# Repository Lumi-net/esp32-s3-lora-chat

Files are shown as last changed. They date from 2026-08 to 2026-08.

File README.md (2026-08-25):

# esp32-s3-lora-chat

**ELC (ESP32-S3 LoRa Chat)** — 基于 ESP32-S3 的 LoRa 点对点聊天设备，支持 T9 键盘输入、LVGL GUI、外部 Flash 存储、WiFi 时间同步和低功耗休眠。

[用户使用手册(凑合看吧 个别地方可能不太对)](USER_MANUAL.md)

PCB见`pcb/`目录，3D模型见`3d/`目录。做的比较粗糙，都是排针连接，因为我不想买一大堆小东西自己焊。

我们使用的各模块品牌（并非打广告，只是为了装配和引脚定义正确，如果你可以自己改代码引脚 重做PCB 重做外壳的话也可以买别的）：
| 模块名称 | 店铺 | 名称 | 备注 |
| --- | ---- | ---- | ---- |
| ESP32-S3开发板 | 深圳市轩特佳电子 | ESP32-S3开发板核心板 ESP32-S3-DevKitC-1 N8R2 N16R8模块板载 | ESP32-S3 N16R8 (随便去淘宝找一家就行。这块板子设计的大家都差不多) |
| LoRa | 泽耀科技 | LoRa模块LLCC68替SX1278射频433无线串口收发模块中继透传远距离 | A39C-T400A22D1a |
| LoRa天线 | 东莞市速波电子有限公司 | lora 433mhz天线470m无线数传315M 510mhz全向高增益外置胶棒SMA | 3DBI 5cm(直头);SMA内针;470-490-510mhz |
| Flash | telesky旗舰店 | W25Q80/16/32/64/128 Flash储存模块 8/16/32/64/128Mbit SPI存储 | W25Q64 |
| LCD | 深圳优智景科技 | 2.4寸TFT LCD显示屏240x320点阵 ST7789驱动高清屏显示屏 | - |
| 键盘 | 欣薇电子企业店 | 4X4矩阵按键 带安装孔 单片机薄膜外扩键盘 直插16按键 | - |

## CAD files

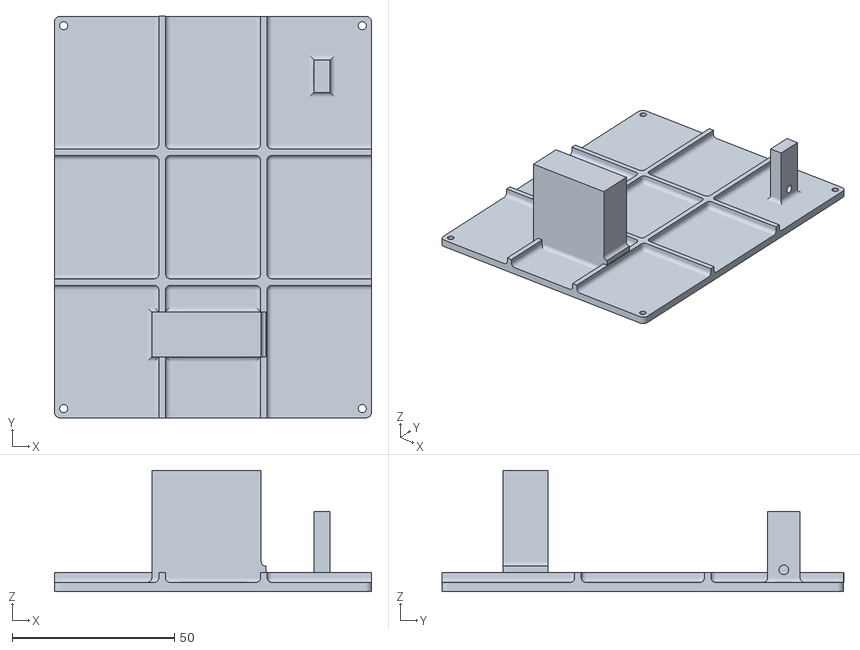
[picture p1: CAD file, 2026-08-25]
3d/底-25.stl
97.8 x 123.9 x 37.3

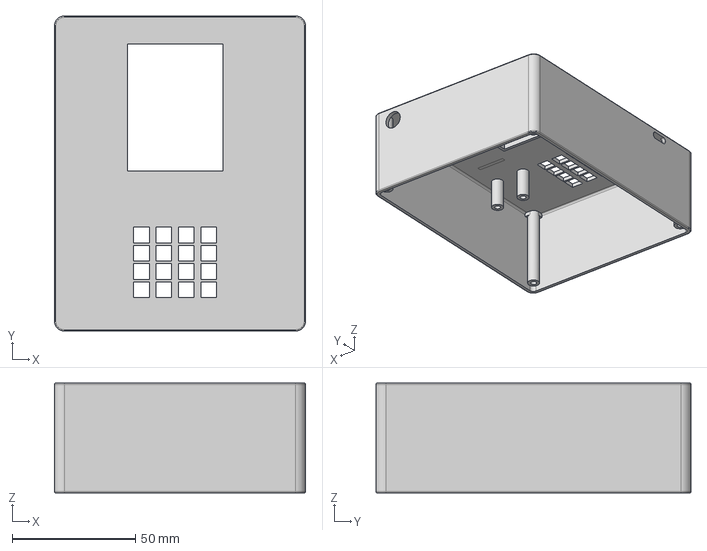
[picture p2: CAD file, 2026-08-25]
3d/esp32-s3-lora-chat.step
102.0 x 128.0 x 44.6 mm

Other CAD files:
3d/大-25.stl
3d/esp32-s3-lora-chat.f3z

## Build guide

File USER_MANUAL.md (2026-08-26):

# ELC (ESP32-S3 LoRa Chat) 用户使用手册

> **Lumi-net** 出品 | 开源 LoRa 点对点通信设备

---

## 目录

- [ELC (ESP32-S3 LoRa Chat) 用户使用手册](#elc-esp32-s3-lora-chat-用户使用手册)
  - [目录](#目录)
  - [1. 快速上手](#1-快速上手)
    - [1.1 前提条件](#11-前提条件)
    - [1.2 开机与启动](#12-开机与启动)
    - [1.3 认识界面](#13-认识界面)
    - [1.4 发送第一条消息](#14-发送第一条消息)
    - [1.5 接收消息](#15-接收消息)
  - [2. 按键操作](#2-按键操作)
    - [2.1 T9 多击输入法](#21-t9-多击输入法)
    - [2.2 锁定/导航模式](#22-锁定导航模式)
  - [3. 界面详解](#3-界面详解)
    - [3.1 状态栏](#31-状态栏)
    - [3.2 菜单页（联系人列表）](#32-菜单页联系人列表)
    - [3.3 聊天页](#33-聊天页)
    - [3.4 输入区域](#34-输入区域)
  - [4. 联系人管理](#4-联系人管理)
    - [4.1 添加联系人](#41-添加联系人)
    - [4.2 删除联系人](#42-删除联系人)
    - [4.3 重命名联系人](#43-重命名联系人)
    - [4.4 联系人 ID 说明](#44-联系人-id-说明)
  - [5. 发送与接收消息](#5-发送与接收消息)
    - [5.1 直发消息](#51-直发消息)
    - [5.2 广播消息（ALL）](#52-广播消息all)
    - [5.3 消息去重](#53-消息去重)
    - [5.4 聊天记录](#54-聊天记录)
  - [6. 设置](#6-设置)
    - [6.1 设置项总览](#61-设置项总览)
    - [6.2 修改联系人别名](#62-修改联系人别名)
    - [6.3 修改用户颜色](#63-修改用户颜色)
    - [6.4 修改界面颜色](#64-修改界面颜色)
    - [6.5 Wi-Fi 配置](#65-wi-fi-配置)
    - [6.6 时间设置](#66-时间设置)
    - [6.7 自动休眠时间](#67-自动休眠时间)
    - [6.8 调节亮度](#68-调节亮度)
    - [6.9 自定义状态栏标题](#69-自定义状态栏标题)
    - [6.10 添加/删除联系人](#610-添加删除联系人)
    - [6.11 清空聊天记录](#611-清空聊天记录)
    - [6.12 恢复出厂设置（清空 NVS）](#612-恢复出厂设置清空-nvs)
    - [6.13 心跳开关](#613-心跳开关)
  - [7. 省电与休眠](#7-省电与休眠)
    - [7.1 自动休眠](#71-自动休眠)
    - [7.2 唤醒方式](#72-唤醒方式)
    - [7.3 快速休眠机制](#73-快速休眠机制)
  - [8. 电池电量](#8-电池电量)
  - [9. 界面颜色自定义](#9-界面颜色自定义)
  - [附录 A：编译与烧录](#附录-a编译与烧录)
    - [环境搭建](#环境搭建)
    - [构建与烧录](#构建与烧录)
    - [关键配置](#关键配置)
  - [附录 B：硬件接线参考](#附录-b硬件接线参考)
    - [主要外设接线](#主要外设接线)
    - [LoRa 模块引脚](#lora-模块引脚)
    - [注意事项](#注意事项)
  - [附录 C：sim\_lora.py 模拟器使用](#附录-csim_lorapy-模拟器使用)
    - [安装依赖](#安装依赖)
    - [基本用法](#基本用法)
    - [交互命令](#交互命令)
    - [示例：测试完整通信流程](#示例测试完整通信流程)
    - [注意事项](#注意事项-1)

---

## 1. 快速上手

### 1.1 前提条件

在使用 ELC 之前，请确认以下事项：

1. **至少准备两台设备**（或一台设备 + 一台运行 `sim_lora.py` 的电脑），单台设备无法进行点对点通信。
2. **设备 ID 已预设**。每台设备有一个唯一的十六进制 ID（如 `0x01`、`0x05`），在固件中硬编码（`self_id` 变量）。如需修改，请重新编译固件。
3. **所有设备使用相同 LoRa 频段和组号**。出厂默认为 470 MHz、组号 `0x00`。如果修改了组号，所有设备必须一致。
4. **建议先设置时间**。消息时间戳依赖 RTC 时钟，未设置时间时消息将显示 `00:00`。

### 1.2 开机与启动

接通电源后，设备显示开机动画：

1. 屏幕中央出现旋转动画（Spinner），下方依次显示初始化状态：
   - `System Booting...`
   - `Initializing Keyboard...`
   - `Initializing UART...`
   - `Initializing Flash...`
   - `Initializing I2C...`
   - `Initializing NVS...`
   - `Reading NVS...`
   - `Restoring Flash Offset...`
   - `Updating Latest Message Time...`
   - `Done!`
2. 初始化完成后自动进入**菜单页**（联系人列表）。

整个启动过程约 3-5 秒。

### 1.3 认识界面

界面分为三个区域：

```
┌─────────────────────────────────┐
│ 10/25 14:30   Lumi-net   🟢 85% │  ← 状态栏（15px）
├─────────────────────────────────┤
│                                 │
│  > Alice        0x01            │
│    02/02 15:37    02/02 14:28   │  ← 在线时间(左) + 消息时间(右)
│                                 │
│    Bob          0x02            │
│    Maybe Offline  No messages   │
│                                 │
│    ...                          │  ← 中间列表区
│                                 │
├─────────────────────────────────┤
│ [S][?]                Please... │  ← 输入区域
│                          112    │
└─────────────────────────────────┘
```

- **状态栏**：左侧显示时间，中间显示标题，右侧显示 LoRa 状态指示灯和电池电量
- **中间列表**：菜单页显示联系人列表，聊天页显示消息记录
- **输入区域**：左侧显示 Shift/Lock 图标和剩余字符数，右侧为文本输入框

### 1.4 发送第一条消息

1. 在菜单页，使用**导航模式**上下选择联系人，按**确认键**进入聊天页。
2. 使用 T9 输入法输入消息（详见 [2.2 节](#22-t9-多击输入法)）。
3. 按 **Shift + CAND4**（即键盘上标有 "SEND" 的位置）发送消息。
4. 等待对方设备确认（ACK）。状态栏指示灯变为**紫色**（等待确认），收到 ACK 后变为**绿色**（空闲）。

### 1.5 接收消息

- 收到消息时，如果当前在聊天页且对象匹配，消息自动追加到列表底部。
- 如果不在聊天页，消息仍然保存到外部闪存（Flash），下次进入聊天页时可查看。

---

## 2. 按键操作

### 2.1 T9 多击输入法

每个键的第一行为小写模式，第二行为大写模式，第三行为导航模式。
```
┌─────┬─────┬─────┬─────┐
│  1abc  │  2def  │  3ghi   │   C1   │
│  !ABC  │  ?DEF  │  'GHI   │        │
│  MENU  │   UP   │SETTINGS │  HOME  │
├─────┼─────┼─────┼─────┤
│  4jkl  │  5mno  │  6pqr  │   C2    │
│  -JKL  │  *MNO  │  /PQR  │         │
│  LEFT  │CONFIRM │  RIGHT │   END   │
├─────┼─────┼─────┼─────┤
│  7stu  │  8vwx  │  9yz(  │   C3    │
│  +STU  │  &VWX  │  ␣YZ)  │         │
│  BACK  │  DOWN  │ DELETE │  PGUP   │
├─────┼─────┼─────┼─────┤
│  SHIFT │  0␣^=  │BACKSPACE│  C4    │
│  SHIFT │  .,:_  │INPUTLOCK│ SEND   │
│  SHIFT │        │BACKSPACE│PGDOWN  │
└─────┴─────┴─────┴─────┘
```

T9 输入法分为两步：**先选键，再选字**。

**第一步：按数字键选键**

按下一个数字键（如 `1`、`2`、`5` 等），屏幕输入区域的锁图标会显示对应的键号（0-9）。此时你已经选中了该键。

**第二步：按候选键选字**

使用C1-C4候选键，选择当前键中的第1-4个候选。

**输入示例**：输入 "Hi"

1. 按 **SHIFT** 键 → Shift 图标变实心（大写模式）
2. 按 `3` 键 → 锁图标显示 `3`（对应字符`'GHI`）
3. 按 **C3** 键 → 选择键 3 的第 3 个候选（Shift 模式），得到 `H`
4. Shift 自动关闭
5. 按 `3` 键 → 锁图标显示 `3`（对应字符 `3ghi`）
6. 按 **C4** 键 → 选择键 3 的第 4 个候选，得到 `i`

### 2.2 锁定导航模式

按下 `Shift + BS` 可切换至锁定导航模式。锁定导航时锁图标显示 `L`。进入锁定导航模式后，需要再次使用`Shift + BS`退出。

锁定模式下，各键变为导航功能：

| 按键 | 功能 |
|---|---|
| `1` | 返回菜单页 |
| `2` | 光标上移 |
| `3` | 进入设置页 |
| `C1` | 光标移至行首（Home） |
| `4` | 光标左移 |
| `5` | **确认/进入**（选择菜单项、进入设置详情） |
| `6` | 光标右移 |
| `C2` | 光标移至行尾（End） |
| `7` | **返回**（从聊天/设置详情返回上级） |
| `8` | 光标下移 |
| `9` | 向前删除（Delete） |
| `C3` | 向上翻页（Page Up） |
| `C4` | 向下翻页（Page Down） |

**典型操作流程**：

1. 开机后在菜单页 → 按 `Shift + BS` 进入锁定模式
2. 按 `2`/`8` 上下选择联系人
3. 按 `5` 确认进入聊天页
4. 再按 `Shift + BS` 退出锁定模式，进入输入模式
5. 输入消息，按 `Shift + C4`（SEND）发送
6. 按 `Shift + BS` 进入锁定模式，按 `1` 或 `7` 返回菜单

---

## 3. 界面详解

### 3.1 状态栏

状态栏位于屏幕最顶部（15px 高），从左到右显示：

| 位置 | 内容 | 说明 |
|---|---|---|
| 左侧 | 时间 `MM/DD HH:MM` | 未设置时间时显示 `Set Time First!` |
| 中间 | 自定义标题 | 默认 `Lumi-net`，最多 16 字符 |
| 右侧 | LoRa 状态指示灯 | 彩色小方块，见下表 |
| 右侧 | 心跳指示灯 | 橙色小方块，仅在心跳**关闭**时显示 |
| 最右 | 电池百分比 | 如 `85%` |

**LoRa 状态指示灯颜色含义**：

| 颜色 | 状态 | 含义 |
|---|---|---|
| 🟢 绿色 | IDLE | 空闲，可收发 |
| 🔵 蓝色 | RECEIVING | 正在接收数据 |
| 🟡 黄色 | SENDING | 正在发送数据 |
| 🟣 紫色 | WAITING_ACK | 已发送，等待对方确认 |
| 🔴 红色 | TIMEOUT | 确认超时，发送失败 |

### 3.2 菜单页（联系人列表）

菜单页是设备的默认首页，显示所有已添加的联系人。

每个联系人显示两行信息：

```
> Alice         0x01          ← 第一行：别名 + 十六进制 ID
  02/02 15:37   02/02 14:28   ← 第二行：在线时间(左) + 消息时间(右)
```

- **光标 `>`** 指示当前选中的联系人
- 每页最多显示 5 个联系人，超出部分可通过翻页查看
- 排序方式：按 ID 从小到大
- 内置联系人 `ALL`（ID `0x00`）始终在列表最前面
- **在线时间**（左侧 `MM/DD HH:MM`）：该联系人最后一次被听到的时间（收到心跳或普通消息均会更新）。如果从未收到过任何通信，显示 `Maybe Offline`。
- **消息时间**（右侧 `MM/DD HH:MM`）：最后一次与该联系人交换消息的时间（发送或接收均会更新）。如果没有消息记录，显示 `No messages`。

### 3.3 聊天页

进入某个联系人的聊天页后，顶部显示标题：

```
CHAT | Alice (0x01)
```

消息列表格式：

```
02/02                     ← 日期分隔线（仅在日期变化时出现）
14:28 Alice: Hello!       ← [时间] [别名]: [消息内容]
14:29 Bob: How are you?   ← 对方消息
14:30 Alice: I'm fine.    ← 我的消息
```

- 消息内容自动换行
- 新消息自动追加到底部并滚动
- 向上滚动可加载更早的消息（每次加载 10 条）

### 3.4 输入区域

屏幕底部的输入区域包含：

```
[S][?]  Please Input...
   112
```

- **Shift 图标 `[S]`**：实心背景表示大写模式已开启，透明背景表示普通模式
- **Lock 图标 `[?]`**：显示 `L` 表示锁定模式，显示数字表示正在选键，显示 `?` 表示普通模式
- **输入框**：显示输入的文本，支持多行
- **剩余字符数**：左下角数字，最大 120 字符

---

## 4. 联系人管理

### 4.1 添加联系人

1. 进入**设置页**（按 `SETTINGS`）
2. 选择 **Add/Remove a contact**，按 `CONFIRM` 确认
3. 输入目标设备的十六进制 ID（如 `02`），按确认
4. 输入该联系人的别名（如 `Bob`），按确认
5. 联系人添加成功，自动返回设置页

**注意事项**：
- ID `0x00`（ALL）和 `0xFF` 为保留值，不允许添加
- 如果输入的 ID 已存在，会进入删除确认流程（见 4.2 节）

### 4.2 删除联系人

1. 在 **Add/Remove a contact** 中输入要删除的联系人 ID
2. 如果该 ID 已存在，设备显示确认提示：

   ```
   Delete contact 0x02 [Bob]?
   Type "0x02Bob" to confirm delete.
   ```

3. 输入 `0x` + ID + 别名（如 `0x02Bob`）进行确认
4. 输入错误则取消删除

**注意**：内置联系人 `ALL`（ID `0x00`）无法删除。

### 4.3 重命名联系人

1. 进入**设置页**
2. 选择 **Change Alias**
3. 输入要修改的联系人 ID，按确认
4. 输入新的别名，按确认
5. 别名更新成功，立即生效

### 4.4 联系人 ID 说明

- 每台设备的 ID 在固件中通过 `self_id` 变量定义（硬编码在 `uart.c` 中）
- 默认 ID 为 `0x01`
- 修改 ID 需要重新编译固件
- 所有设备的 ID 必须互不相同
- 只有添加了别名的联系人才会出现在菜单中；未添加别名的 ID 不会显示
- 收到来自未知 ID 的消息时，消息写入 Flash 但不更新菜单；后续手动添加该 ID 为联系人后，聊天页会从 Flash 加载历史消息

---

## 5. 发送与接收消息

### 5.1 直发消息

直发消息是点对点通信，需要对方设备自动确认收到（ACK）。

**发送流程**：
1. 进入目标联系人的聊天页
2. 输入消息（最多 120 字符）
3. 按 **Shift + C4**（SEND）发送
4. 状态栏指示灯变为**紫色**（等待 ACK）
5. 3 秒内收到 ACK → 消息保存成功，指示灯恢复**绿色**
6. 3 秒内未收到 ACK → 自动重试，最多重试 5 次
7. 5 次均超时 → 显示错误提示 `Message failed to send!`

**注意事项**：
- 发送期间（等待 ACK 时）无法发送新消息
- 对方设备需要在线且在通信范围内，否则会发送失败。
- 即使对方设备未将你添加为联系人，消息仍然会被接收，但不会自动出现在菜单中（无法看到）。如果之后对方手动添加你的 ID 为联系人，打开聊天页时会从 Flash 加载历史消息并显示。

### 5.2 广播消息（ALL）

广播消息发送给所有设备，无需确认ACK。

1. 在菜单页选择 **ALL**（ID `0x00`）进入聊天页
2. 输入消息并发送
3. 消息立即保存到本地 Flash，无需等待 ACK
4. 通信范围内所有设备均可收到

**广播消息特点**：
- 不需要对方确认
- 不保证送达
- 消息同时保存在本地和对方设备（若能收到）

### 5.3 消息去重

设备通过序列号（seq）机制自动去除重复消息。如果同一条消息因重试等原因被多次接收，只有第一条会被处理，后续重复消息被静默丢弃。

### 5.4 聊天记录

- 所有收发的消息都保存在外部 SPI Flash（约 8MB）
- 采用 A/B 块磨损均衡机制，延长 Flash 寿命
- 开机时自动扫描恢复写入位置
- 支持跨 A/B 块的连续读取
- 可在设置中清空聊天记录（需输入确认码）

---

## 6. 设置

### 6.1 设置项总览

| # | 设置项 | 功能简述 |
|---|---|---|
| 0 | Change Alias | 修改联系人显示名称 |
| 1 | Change User Color | 修改联系人消息颜色 |
| 2 | Change Interface Color | 修改界面主题颜色（6 个可配置项） |
| 3 | Wi-Fi (For Time) | 配置 Wi-Fi 用于时间同步 |
| 4 | Time | 手动设置时间或通过 Wi-Fi NTP 同步 |
| 5 | Auto Sleep Time | 设置自动休眠超时时间（秒） |
| 6 | Change Brightness | 调节屏幕亮度（10-100） |
| 7 | Customize Title | 自定义状态栏标题（最多 16 字符） |
| 8 | Add/Remove a contact | 添加或删除联系人 |
| 9 | Clear Chat History | 清空外部 Flash 中的聊天记录 |
| 10 | Clear NVS Data | 恢复出厂设置（清除所有设置，重启） |
| 11 | Heartbeat Enable | 开启/关闭心跳广播 |

### 6.2 修改联系人别名

1. 设置页 → **Change Alias** → 确认
2. 输入目标联系人的十六进制 ID（如 `01`）→ 确认
3. 输入新的别名（最多 16 字符）→ 确认
4. 别名立即生效

**注意**：如果输入的 ID 不存在，会提示 `Invalid ID!`。

### 6.3 修改用户颜色

为每个联系人设置独特的消息显示颜色。

1. 设置页 → **Change User Color** → 确认
2. 输入目标联系人的十六进制 ID → 确认
3. 输入 6 位十六进制颜色值（如 `00FF00` 表示绿色）→ 确认

颜色值格式：`RRGGBB`（红绿蓝各 2 位十六进制）。

### 6.4 修改界面颜色

界面有 6 个可配置颜色项：

| 索引 | 名称 | 说明 |
|---|---|---|
| 0 | COLOR_BACKGROUND | 页面背景色 |
| 1 | COLOR_MSG_TEXT | 消息文本颜色 |
| 2 | COLOR_MSG_TIME | 消息时间标签颜色 |
| 3 | COLOR_MSG_DATE | 日期分隔线颜色 |
| 4 | COLOR_STATUS_BAR | 状态栏背景色 |
| 5 | COLOR_TEXTAREA_BACKGROUND | 输入框背景色 |

操作步骤：
1. 设置页 → **Change Interface Color** → 确认
2. 输入颜色索引（0-5）→ 确认
3. 输入 6 位十六进制颜色值 → 确认

### 6.5 Wi-Fi 配置

Wi-Fi 仅用于时间同步（NTP），不用于消息传输。

**方式一：手动输入 SSID 和密码**

1. 设置页 → **Wi-Fi (For Time)** → 确认
2. 输入 Wi-Fi 名称（SSID，最多 32 字符）→ 确认
3. 输入 Wi-Fi 密码（至少 8 位）→ 确认
4. 设备自动连接 Wi-Fi，同步时间后关闭 Wi-Fi

**方式二：热点配网（Soft-AP）**

1. 设置页 → **Wi-Fi (For Time)** → 确认
2. **不输入任何内容**，直接按确认
3. 设备启动热点 `ESP32S3_Config`，屏幕显示随机密码
4. 用手机连接该热点，打开浏览器访问 `192.168.4.1`
5. 在网页中输入目标 Wi-Fi 的 SSID 和密码，提交
6. 设备自动切换到 STA 模式连接 Wi-Fi，同步时间后关闭

**注意事项**：
- 热点模式有 5 分钟超时，超时后自动关闭
- Wi-Fi 连接成功后会自动关闭以节省电量
- 时间同步使用 `ntp.aliyun.com`（主）和 `pool.ntp.org`（备）

### 6.6 时间设置

**手动设置**：
1. 设置页 → **Time** → 确认
2. 输入格式：`YYYYMMDDHHMMSS`（如 `20260202114514` 表示 2026 年 2 月 2 日 11:45:14）
3. 按确认，时间立即生效

**Wi-Fi NTP 同步**：
1. 设置页 → **Time** → 确认
2. **不输入任何内容**，直接按确认
3. 设备自动连接已保存的 Wi-Fi 并同步时间
4. 同步成功后显示 `Time Synced!`，Wi-Fi 自动关闭

时区固定为 UTC+8（中国标准时间）。

### 6.7 自动休眠时间

设置设备无操作后自动进入休眠的超时时间。

1. 设置页 → **Auto Sleep Time** → 确认
2. 输入超时秒数（如 `300` 表示 5 分钟）
3. 按确认

默认值为 300 秒（5 分钟）。设为 0 可禁用自动休眠。我们不建议禁用自动休眠，因为这将会非常耗电。

### 6.8 调节亮度

1. 设置页 → **Change Brightness** → 确认
2. 输入亮度值（10-100，如 `50`）
3. 按确认，亮度立即生效

亮度值 10 为最暗，100 为最亮。设置保存在 NVS 中，重启后仍然有效。

### 6.9 自定义状态栏标题

1. 设置页 → **Customize Title** → 确认
2. 输入新标题（最多 16 字符）
3. 按确认，标题立即更新

默认标题为 `Lumi-net`。

### 6.10 添加/删除联系人

详见 [第 4 章](#4-联系人管理)。

### 6.11 清空聊天记录

此操作会擦除整个外部 Flash 芯片（约 8MB），**所有聊天记录将永久丢失**。

1. 设置页 → **Clear Chat History** → 确认
2. 屏幕显示随机 4 位确认码（如 `A3F2`）
3. 输入 `CLEAR FLASH` + 空格 + 确认码（如 `CLEAR FLASH A3F2`）
4. 按确认，开始擦除（约 1 分钟）
5. 擦除完成后显示 `Flash cleared.`

**请谨慎操作！此操作不可逆。**

### 6.12 恢复出厂设置（清空 NVS）

此操作会清除所有 NVS 存储的设置（别名、颜色、亮度、Wi-Fi 配置等），并自动重启设备。

1. 设置页 → **Clear NVS Data** → 确认
2. 屏幕显示随机 4 位确认码
3. 输入 `CLEAR NVS` + 空格 + 确认码
4. 按确认，设备清除 NVS 后自动重启

**注意**：重启后所有设置恢复默认值，但聊天记录（存储在外部 Flash）不受影响。

### 6.13 心跳开关

心跳广播用于让其他设备知道你在线，默认开启，但关闭可以省电。

1. 设置页 → **Heartbeat Enable** → 确认
2. 屏幕显示当前状态（`ON` 或 `OFF`）
3. 按确认切换状态

- 开启时：设备每 3-4 分钟自动发送一次心跳广播
- 关闭时：状态栏显示橙色指示灯作为警告
- 心跳关闭后，其他设备将无法看到你的在线状态

---

## 7. 省电与休眠

### 7.1 自动休眠

设备在无操作超过设定时间（默认 300 秒）后自动进入睡眠模式。

进入休眠前的条件：
- 无待发送/待确认的消息
- Wi-Fi 处于空闲状态
- 无按键按下、无 LoRa 数据收发

休眠时：
- 屏幕背光关闭
- CPU 进入低功耗模式
- LoRa 模块进入休眠
- RTC 时钟继续运行

### 7.2 唤醒方式

| 唤醒源 | 触发条件 | 行为 |
|---|---|---|
| 键盘（EXT1） | 任意按键按下 | 亮屏 |
| LoRa AUX（EXT0） | AUX 引脚（GPIO21）变低 | 不亮屏，但保持唤醒 5 秒以处理消息 |
| 定时器 | 心跳发送时间 | 不亮屏，发送完心跳重新休眠 |

### 7.3 快速休眠机制

当设备被 LoRa AUX 或定时器唤醒时，会启动一个 5 秒的"快速休眠截止时间"：
- 在这 5 秒内收到新消息 → 重新计时 5 秒
- 5 秒内无活动 → 自动重新休眠
- 键盘唤醒不触发此机制，保持唤醒直到超时

---

## 8. 电池电量

ELC 支持 INA219 电流/电压传感器（I2C 地址 `0x40`），可监测电池电量。

- 电量每 30 秒更新一次
- 显示在状态栏最右侧（如 `85%`）
- 电压范围：3.30V（0%）至 4.20V（100%）
- 电量变化小于 1% 时不更新显示（防抖动）
- LoRa 发送或 Wi-Fi 活动期间跳过读取（避免电压跌落导致误判）

---

## 9. 界面颜色自定义

ELC 支持完全自定义界面颜色。所有颜色以 6 位十六进制值（`RRGGBB`）存储在 NVS 中。

**可配置的颜色项**：

| 索引 | NVS 键名 | 说明 | 默认值 |
|---|---|---|---|
| 0 | ic_0 | 背景色 | 深色 |
| 1 | ic_1 | 消息文本色 | 白色 |
| 2 | ic_2 | 消息时间色 | 灰色 |
| 3 | ic_3 | 日期分隔线色 | 灰色 |
| 4 | ic_4 | 状态栏背景色 | 深色 |
| 5 | ic_5 | 输入框背景色 | 深色 |

**每个联系人也有独立的颜色**（用户颜色），用于在聊天中区分不同人的消息。

修改方式详见 [6.3 节](#63-修改用户颜色) 和 [6.4 节](#64-修改界面颜色)。

---

## 附录 A：编译与烧录

### 环境搭建

请参考 [ESP-IDF 官方安装指南](https://docs.espressif.com/projects/esp-idf/en/latest/esp32s3/get-started/)。

推荐下载 `.zst` 离线安装包，避免在线安装的网络问题。

### 构建与烧录

```bash
# 设置目标芯片
idf.py set-target esp32s3

# 编译
idf.py build

# 烧录并打开串口监视器（替换 PORT 为实际串口号，如 COM7、/dev/ttyUSB0）
idf.py -p PORT flash monitor
```

### 关键配置

| 配置项 | 值 | 说明 |
|---|-----|---|
| Flash Size | 16MB (QIO 80MHz) | 外部 Flash 容量 |
| 分区表 | `partitions_user.csv` | 自定义分区（factory app @ 0x10000, 4MB） |
| PSRAM | 启用 | LVGL 显示缓冲使用 PSRAM |

---

## 附录 B：硬件接线参考

### 主要外设接线

| 外设 | GPIO | 功能 | 说明 |
|---|---|---|---|
| **键盘行** | GPIO 5, 6, 7, 4 | 输出（开漏） | 矩阵键盘行线 |
| **键盘列** | GPIO 16, 17, 18, 8 | 输入（上拉） | 矩阵键盘列线，支持 EXT1 唤醒 |
| **LoRa UART TX** | GPIO 19 | UART1 TX | 连接 LoRa 模块 RX |
| **LoRa UART RX** | GPIO 20 | UART1 RX | 连接 LoRa 模块 TX |
| **LoRa MD0** | GPIO 47 | 输出 | 模式控制 0 |
| **LoRa MD1** | GPIO 48 | 输出 | 模式控制 1 |
| **LoRa AUX** | GPIO 21 | 输入（上拉） | 模块状态指示，支持 EXT0 唤醒 |
| **LCD SPI MOSI** | GPIO 11 | SPI2 MOSI | LCD 数据线 |
| **LCD SPI SCLK** | GPIO 12 | SPI2 SCLK | LCD 时钟线 |
| **LCD CS** | GPIO 10 | 输出 | LCD 片选 |
| **LCD DC** | GPIO 13 | 输出 | LCD 数据/命令选择 |
| **LCD Reset** | GPIO 14 | 输出 | LCD 复位 |
| **LCD 背光** | GPIO 9 | LEDC PWM | 亮度控制 |
| **Flash MISO** | GPIO 41 | SPI3 MISO | 外部 Flash 数据输入 |
| **Flash MOSI** | GPIO 38 | SPI3 MOSI | 外部 Flash 数据输出 |
| **Flash CLK** | GPIO 39 | SPI3 CLK | 外部 Flash 时钟 |
| **Flash CS** | GPIO 40 | 输出 | 外部 Flash 片选 |
| **I2C SDA** | GPIO 42 | I2C 数据 | INA219 电池传感器 |
| **I2C SCL** | GPIO 2 | I2C 时钟 | INA219 电池传感器 |
| **INA219 电源** | GPIO 1 | 输出 | 传感器供电控制 |

### LoRa 模块引脚

| 模块引脚 | 连接目标 |
|---|---|
| VCC | 3.3V |
| GND | GND |
| TXD | GPIO 20（UART1 RX） |
| RXD | GPIO 19（UART1 TX） |
| MD0 | GPIO 47 |
| MD1 | GPIO 48 |
| AUX | GPIO 21 |

### 注意事项

1. **电压**：ESP32-S3 GPIO 为 3.3V 逻辑，不可直接连接 5V 设备
2. **SPI 总线**：LCD 使用 SPI2 总线，外部 Flash 使用 SPI3 总线
3. **LoRa 模块配置**：模块需预先配置为定点透传模式、信道3C（470MHz）、本地ID（应与ESP32-S3相同）、唤醒时长
4. **键盘矩阵**：行线为开漏输出，列线上拉，按键按下时列线被拉低
5. **AUX 引脚**：LoRa 模块空闲时为高电平，有数据时变低，用于唤醒和状态检测

---

## 附录 C：sim_lora.py 模拟器使用

`sim_lora.py` 是一个 Python 脚本，通过 USB-UART 连接 LoRa 模块，模拟第二台 ELC 设备，用于测试通信功能。

### 安装依赖

```bash
pip install pyserial
```

### 基本用法

```bash
# 使用默认设置（self_id=0x05）连接 COM5
python sim_lora.py COM5

# 指定 self_id 为 0x03
python sim_lora.py COM5 --self-id 0x03

# 列出可用串口
python sim_lora.py --list-ports
```

### 交互命令

| 命令 | 说明 |
|---|---|
| `<文本>` | 发送消息给当前目标 |
| `/to <hex>` | 切换发送目标。`01`-`FE` 为定点发送（需对方 ACK），`00` 或 `FF` 为广播（无需 ACK） |
| `/hb` | 手动发送一次心跳（广播至 `0xFF`） |
| `/stats` | 显示收发统计（TX/RX/ACK 计数） |
| `/help` | 显示帮助 |
| `/q` | 退出 |

### 示例：测试完整通信流程

```bash
# 终端 1：启动模拟器，ID 为 0x05
python sim_lora.py COM5 --self-id 0x05

# 终端 2：与 ELC 设备（ID 0x01）对话
# 在模拟器中：
> /to 01              # 切换目标到 ELC 设备
> Hello from PC!      # 发送消息
# ELC 设备应收到消息并自动回复 ACK

# 在 ELC 设备上：
# 进入 ALL 聊天页，发送广播消息
# 模拟器应收到广播
```

### 注意事项

1. **LoRa 模块配置**：模块需预先配置为定点透传模式
2. **波特率**：默认 9600bps，8N1 格式，与固件一致（可通过 `--baud` 参数修改）
3. **自动 ACK**：收到发给本机的单播消息时自动回复 ACK；收到广播消息（目标 `0x00` 或 `0xFF`）时不回复
4. **自动心跳**：后台每 180-240 秒（随机间隔）自动发送一次心跳广播，也可通过 `/hb` 手动触发
5. **帧格式**：与固件完全一致，完整线上包结构如下：

```
[routing 3B] + [AA 55] + [seq] + [self_id] + [target_id] + [timestamp 4B] + [data_len] + [data 0-120B] + [CRC8]
```

- **routing**：3 字节路由头（`[group, target, channel]`，广播时为 `[0xFF, 0xFF, 0x3C]`）
- **AA 55**：帧头标识
- **seq**：序列号（用于消息去重）
- **self_id / target_id**：发送方 / 接收方 ID
- **timestamp**：4 字节时间戳（月,日,时,分）
- **data_len**：数据长度（0-120）
- **CRC8**：校验码（多项式 x^8+x^5+x^4+1，初始值 0）

---

*本手册适用于 ELC (ESP32-S3 LoRa Chat) 固件版本。如有更新，请以最新版本为准。*

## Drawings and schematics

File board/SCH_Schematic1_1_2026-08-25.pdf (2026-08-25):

## KEY1

# LoRa 1

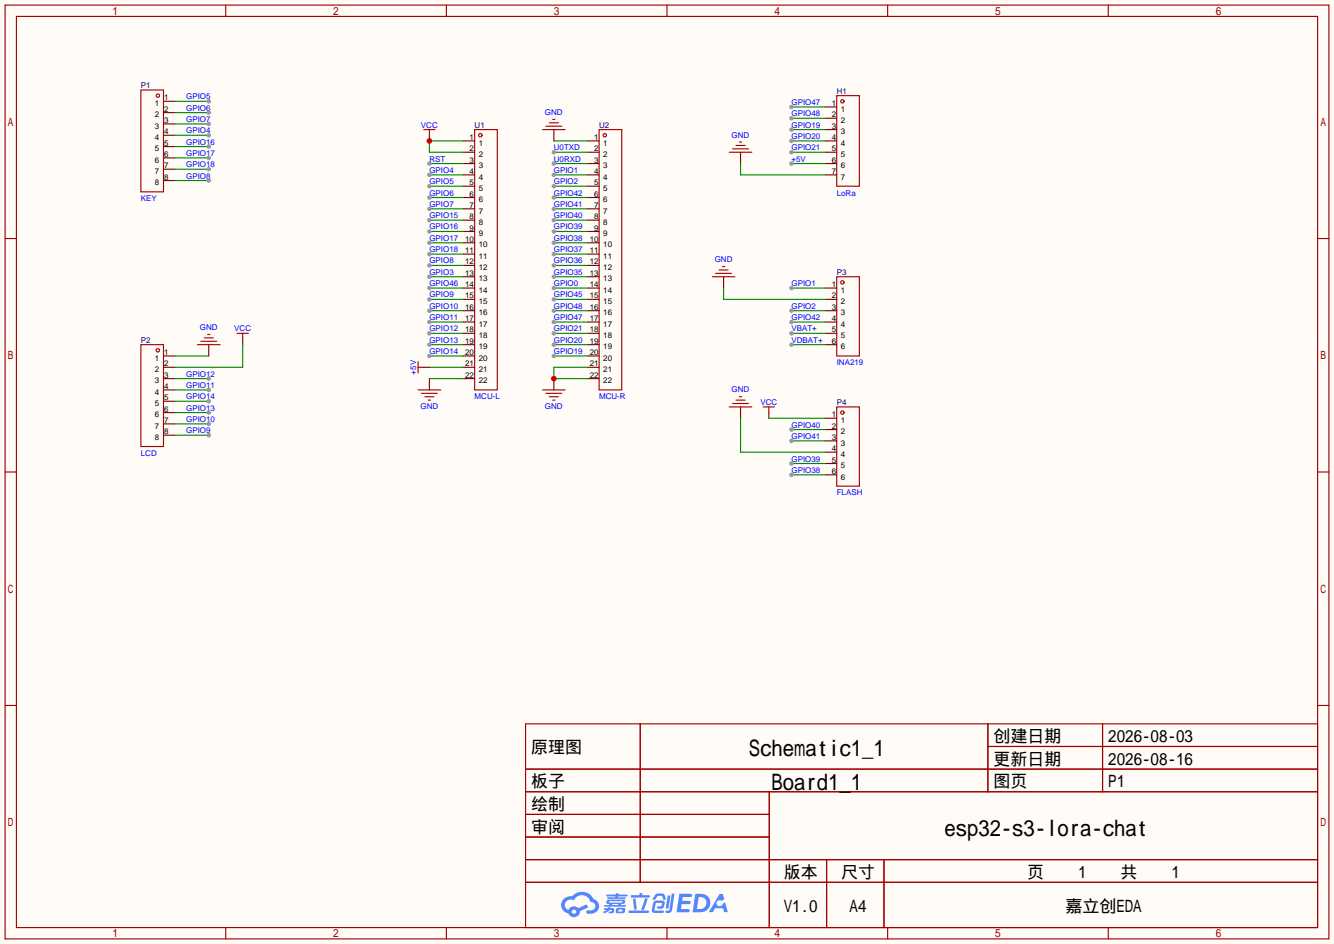
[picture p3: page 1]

原理图 | Schematic1_1 | 创建日期 | 2026-08-03

更新日期 | 2026-08-16

绘制 | esp32-s3-lora-chat
审阅

V1.0 | A4 | 嘉立创EDA

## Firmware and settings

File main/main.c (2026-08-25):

#include <stdio.h>
#include <stdbool.h>
#include <sys/time.h>
#include "freertos/FreeRTOS.h"
#include "freertos/task.h"
#include "driver/gpio.h"
#include "driver/uart.h"
#include "esp_heap_caps.h"
#include "esp_log.h"
#include "pwm.h"
#include "spi.h"
#include "freertos/semphr.h"
#include "uart.h"
#include "lcd.h"
#include "ui.h"
#include "va.h"
#include "key.h"
#include "i2c.h"
#include "flash.h"
#include "sleep.h"
#include "mynvs.h"
#include "wifi.h"
#include "jbm12.h"

#define INIT_DONE_BIT (1 << 0)             // 定义初始化完成的事件位
#define ACK_TIMEOUT_MS 3000                // ACK 超时时间为 3 秒
#define WIFI_AP_TIMEOUT_MS (5 * 60 * 1000) // AP 配网超时时间 5 分钟

static SemaphoreHandle_t lvgl_mutex = NULL;
static EventGroupHandle_t init_event_group;
static lv_obj_t *scr_loading = NULL; // 用于保存开机动画界面对象，以便后续释放内存
lv_obj_t *boot_text_label;

static SendState send_state = SEND_STATE_IDLE;
static uint8_t pending_ack_seq = 0;       // 记录等待匹配的随机数
static uint8_t pending_target_id = 0;     // 缓存目标ID，用于收到ACK后写Flash
static uint32_t send_start_time = 0;      // 记录发送开始的时间戳
static char pending_payload[121] = {0};   // 缓存发送的内容
static uint32_t retry_delay_end_time = 0; // 重试间隔结束时间 (0=不等待)
static uint8_t last_seen_seq[256];        // 每个 self_id 最后收到的 seq (去重用)
static bool seen_peer[256];               // 记录是否曾收到该 self_id 的消息
static uint32_t ap_start_tick = 0;        // AP 配网启动时刻 (ms), 0=未在配网

static void update_boot_label_cb(void *arg)
{
    char *text = (char *)arg;
    if (boot_text_label != NULL && text != NULL)
    {
        lv_label_set_text(boot_text_label, text);
    }
}

static void async_boot_label(const char *text)
{
    if (lvgl_mutex)
        xSemaphoreTakeRecursive(lvgl_mutex, portMAX_DELAY);
    lv_async_call(update_boot_label_cb, (void *)text);
    if (lvgl_mutex)
        xSemaphoreGiveRecursive(lvgl_mutex);
}

static void lvgl_tick_cb(void *arg)
{
    lv_tick_inc(1);
}

void app_main_task(void *arg)
{
    UIEvent event;
    uint8_t key;
    bool is_initialized = false;
    WifiProvisioningState current_wifi_state = WIFI_STATE_IDLE;
    int64_t quick_sleep_deadline_us = 0;
    uint32_t last_battery_check_time = 0;
    uint32_t last_time_check_time = 0;
    uint32_t last_mem_check_time = 0;
    uint8_t current_soc = 100;
    uint32_t sntp_start_time = 0;

    while (1)
    {
        // 非阻塞检查外设是否初始化完成，进行 UI 切换
        if (!is_initialized)
        {
            EventBits_t bits = xEventGroupGetBits(init_event_group);
            if (bits & INIT_DONE_BIT)
            {
                ESP_LOGI("APP", "IC!1");
                is_initialized = true;
                last_activity_time_us = esp_timer_get_time();
                lv_label_set_text(boot_text_label, "Done!");
                ESP_LOGI("APP", "IC!2");

                create_ui();
                ESP_LOGI("APP", "IC!3");
                // 切换到菜单页面
                ui_show_menu_page();
                ESP_LOGI("APP", "IC!4");

                // 释放开机动画界面的内存，防止内存泄漏
                scr_loading = NULL;
                boot_text_label = NULL;

                ESP_LOGI("APP", "IC!5");
                xTaskCreatePinnedToCore(scanKeyTask, "scan_key", 2048, NULL, 5, NULL, 0);
                xTaskCreatePinnedToCore(uart_receive, "uart_receive", 4096, NULL, 5, NULL, 0);
                heartbeat_init();
            }
        }

        // 只有在初始化完成后，才处理业务事件 (避免初始化期间处理无效数据)
        if (is_initialized)
        {
            // 等待 ACK
            if (send_state == SEND_STATE_WAITING_ACK)
            {
                uint32_t current_time = xTaskGetTickCount() * portTICK_PERIOD_MS;

                if (retry_delay_end_time > 0)
                {
                    if (current_time >= retry_delay_end_time)
                    {
                        retry_delay_end_time = 0;
                        lora_status = LORA_STATUS_SENDING;
                        update_lora_status_indicator();
                        uint8_t frame_buf[131];
                        uint8_t frame_len = buildLoRaFrame(frame_buf, self_id, pending_target_id, pending_payload);
                        frame_buf[2] = pending_ack_seq;
                        frame_buf[10 + frame_buf[9]] = calculateCRC8(&frame_buf[2], 8 + frame_buf[9]);
                        send_lora_packet(pending_target_id, frame_buf, frame_len);
                        lora_status = LORA_STATUS_WAITING_ACK;
                        update_lora_status_indicator();
                        send_start_time = current_time;
                    }
                }
                else if (current_time - send_start_time >= ACK_TIMEOUT_MS)
                {
                    ack_timeout_count++;
                    ESP_LOGW("APP", "ACK timeout %d/5! seq: %d", ack_timeout_count, pending_ack_seq);
                    if (ack_timeout_count >= 5)
                    {
                        send_state = SEND_STATE_IDLE;
                        lora_status = LORA_STATUS_IDLE;
                        ack_timeout_count = 0;
                        update_lora_status_indicator();
                        char toast_string[256];
                        snprintf(toast_string, sizeof(toast_string), "Message failed to send! \nPlease check if the recipient is online!");
                        show_toast_dialog(toast_string, 8000);
                    }
                    else
                    {
                        lora_status = LORA_STATUS_TIMEOUT;
                        update_lora_status_indicator();
                        retry_delay_end_time = current_time + 500;
                    }
                }
            }
            // 读队列
            if (xQueueReceive(appQueue, &event, 0))
            {
                if (event.type == EVENT_UART)
                {
                    if (event.frame.data_len == 0)
                    { // 收到ACK 说明自己发出去了
                        if (send_state == SEND_STATE_WAITING_ACK && event.frame.seq == pending_ack_seq)
                        {
                            ESP_LOGI("APP", "ACK received! seq: %d", pending_ack_seq);
                            send_state = SEND_STATE_IDLE;
                            ack_timeout_count = 0;
                            retry_delay_end_time = 0;

                            // 写Flash
                            LoRaFrameData msg_frame = {0};
                            msg_frame.self_id = self_id;
                            msg_frame.target_id = pending_target_id;

                            struct timeval tv;
                            gettimeofday(&tv, NULL);
                            struct tm *timeinfo = localtime(&tv.tv_sec);
                            if (timeinfo->tm_year >= (2024 - 1900))
                            {
                                msg_frame.month = timeinfo->tm_mon + 1; // tm_mon 范围是 0-11，需要 +1
                                msg_frame.day = timeinfo->tm_mday;      // tm_mday 范围是 1-31
                                msg_frame.hour = timeinfo->tm_hour;     // tm_hour 范围是 0-23
                                msg_frame.minute = timeinfo->tm_min;    // tm_min 范围是 0-59
                            }
                            else
                            {
                                msg_frame.month = 0;
                                msg_frame.day = 0;
                                msg_frame.hour = 0;
                                msg_frame.minute = 0;
                                ESP_LOGW("APP", "RTC time not synced yet, sending 00:00");
                            }

                            uint16_t pld_len = strlen(pending_payload); // payload_len
                            if (pld_len > 129)
                                pld_len = 129;

                            msg_frame.data_len = pld_len;
                            memcpy(msg_frame.data_str, pending_payload, pld_len);
                            msg_frame.data_str[pld_len] = '\0'; // 确保字符串闭合

                            msg_frame.checksum = calculateCRC8(
                                (const uint8_t *)&msg_frame,
                                offsetof(LoRaFrameData, data_str) + msg_frame.data_len);

                            uint32_t sent_packed = (uint32_t)msg_frame.month * 1000000 +
                                                   (uint32_t)msg_frame.day * 10000 +
                                                   (uint32_t)msg_frame.hour * 100 +
                                                   (uint32_t)msg_frame.minute;
                            if (sent_packed > chat_list[pending_target_id].last_time)
                            {
                                chat_list[pending_target_id].last_time = sent_packed;
                                if (current_page_id == PAGE_MENU)
                                    menu_refresh();
                            }

                            esp_err_t err = chat_storage_append(&msg_frame);
                            if (err != ESP_OK)
                            {
                                ESP_LOGE("FLASH", "Save chat failed: %s", esp_err_to_name(err));
                                char toast_string[256];
                                snprintf(toast_string, sizeof(toast_string), "Writing Flash Failed! \nPlease contact developer. \nError Code: %s", esp_err_to_name(err));
                                show_toast_dialog(toast_string, 8000);
                            }
                            else
                            {
                                ESP_LOGI("FLASH", "Chat saved to flash, len: %d", pld_len);
                            }

                            // 更新UI
                            lv_textarea_set_text(g_ta, "");
                            input_remaining_chars = 120;
                            lv_label_set_text_fmt(input_cnt_left, "%d", input_remaining_chars);
                            ui_chat_append_new_message(&msg_frame);
                            lora_status = LORA_STATUS_IDLE;
                            update_lora_status_indicator();
                        }
                        else
                        {
                            lora_status = LORA_STATUS_IDLE;
                            update_lora_status_indicator();
                        }
                    }
                    else
                    {
                        if (event.frame.target_id == 0xFF && event.frame.data_len >= 2 && strncmp(event.frame.data_str, "HB", 2) == 0) // 收到心跳
                        {
                            // 收到心跳广播：更新时间戳
                            if (event.frame.self_id != self_id)
                            {
                                struct timeval tv;
                                gettimeofday(&tv, NULL);
                                struct tm *timeinfo = localtime(&tv.tv_sec);
                                uint32_t online_packed;
                                if (timeinfo->tm_year >= (2024 - 1900))
                                {
                                    online_packed =
                                        (uint32_t)(timeinfo->tm_mon + 1) * 1000000 +
                                        (uint32_t)timeinfo->tm_mday * 10000 +
                                        (uint32_t)timeinfo->tm_hour * 100 +
                                        (uint32_t)timeinfo->tm_min;
                                }
                                else
                                {
                                    online_packed =
                                        (uint32_t)event.frame.month * 1000000 +
                                        (uint32_t)event.frame.day * 10000 +
                                        (uint32_t)event.frame.hour * 100 +
                                        (uint32_t)event.frame.minute;
                                }
                                chat_list[event.frame.self_id].last_online = online_packed;
                                chat_list[0x00].last_online = online_packed;
                                if (current_page_id == PAGE_MENU)
                                    menu_refresh();
                            }
                            lora_status = LORA_STATUS_IDLE;
                            update_lora_status_indicator();
                        }
                        else
                        { // 收到消息 UART收到消息会先发ACK再传队列 这里不需要发了
                            if (event.frame.data_len > 0 && seen_peer[event.frame.self_id] && last_seen_seq[event.frame.self_id] == event.frame.seq)
                            {
                                ESP_LOGI("APP", "Dup msg from %02X seq=%d, skip", event.frame.self_id, event.frame.seq);
                            }
                            else
                            {
                                seen_peer[event.frame.self_id] = true;
                                last_seen_seq[event.frame.self_id] = event.frame.seq;
                                uint32_t packed = (uint32_t)event.frame.month * 1000000 +
                                                  (uint32_t)event.frame.day * 10000 +
                                                  (uint32_t)event.frame.hour * 100 +
                                                  (uint32_t)event.frame.minute;
                                if (packed > chat_list[event.frame.self_id].last_time)
                                {
                                    chat_list[event.frame.self_id].last_time = packed;
                                    if (current_page_id == PAGE_MENU)
                                        menu_refresh();
                                }
                                struct timeval tv_now;
                                gettimeofday(&tv_now, NULL);
                                struct tm *tm_now = localtime(&tv_now.tv_sec);
                                uint32_t online_packed;
                                if (tm_now->tm_year >= (2024 - 1900))
                                {
                                    online_packed =
                                        (uint32_t)(tm_now->tm_mon + 1) * 1000000 +
                                        (uint32_t)tm_now->tm_mday * 10000 +
                                        (uint32_t)tm_now->tm_hour * 100 +
                                        (uint32_t)tm_now->tm_min;
                                }
                                else
                                {
                                    online_packed =
                                        (uint32_t)event.frame.month * 1000000 +
                                        (uint32_t)event.frame.day * 10000 +
                                        (uint32_t)event.frame.hour * 100 +
                                        (uint32_t)event.frame.minute;
                                }
                                chat_list[event.frame.self_id].last_online = online_packed;

                                // ALL 广播消息：同时更新 ALL 条目的时间
                                if (event.frame.target_id == 0x00)
                                {
                                    if (packed > chat_list[0x00].last_time)
                                    {
                                        chat_list[0x00].last_time = packed;
                                    }
                                    chat_list[0x00].last_online = online_packed;
                                }
                                esp_err_t err = chat_storage_append(&event.frame);
                                if (err != ESP_OK)
                                {
                                    ESP_LOGE("FLASH", "Save chat failed: %s", esp_err_to_name(err));
                                    char toast_string[256];
                                    snprintf(toast_string, sizeof(toast_string), "Writing Flash Failed! \nPlease contact developer. \nError Code: %s", esp_err_to_name(err));
                                    show_toast_dialog(toast_string, 8000);
                                }
                                else
                                {
                                    ESP_LOGI("FLASH", "Chat saved to flash, len: %d", event.frame.data_len);
                                }

                                if (g_chat_target_id == event.frame.self_id ||
                                    (g_chat_target_id == 0x00 && event.frame.target_id == 0x00))
                                {
                                    ui_chat_append_new_message(&event.frame);
                                }
                                lora_status = LORA_STATUS_IDLE;
                                update_lora_status_indicator();
                            }
                        }
                    }
                }
                else if (event.type == EVENT_KEY)
                {
                    key = event.key;
                    switch (key)
                    {
                    case 20: // KEY_STATE_CHANGE sentinel
                        break;
                    case 19: // LOCK_TOGGLE sentinel
                        break;
                    case 8: // BS
                        lv_textarea_delete_char(g_ta);
                        size_t talen = strlen(lv_textarea_get_text(g_ta));
                        input_remaining_chars = 120 - talen;
                        lv_label_set_text_fmt(input_cnt_left, "%d", input_remaining_chars);
                        break;
                    case 17: // SEND
                    {
                        if (current_page_id != PAGE_CHAT)
                            break;
                        if (send_state != SEND_STATE_IDLE)
                        { // 正在等待ACK
                            ESP_LOGW("APP", "Busy waiting for ACK, ignore send.");
                            break;
                        }
                        const char *payload = lv_textarea_get_text(g_ta);
                        uint8_t frame_buf[131];
                        uint8_t lora_target = (g_chat_target_id == 0x00) ? 0xFF : g_chat_target_id;
                        uint8_t frame_len = buildLoRaFrame(frame_buf, self_id, g_chat_target_id, payload);
                        lora_status = LORA_STATUS_SENDING;
                        update_lora_status_indicator();
                        send_lora_packet(lora_target, frame_buf, frame_len);

                        if (g_chat_target_id == 0x00)
                        {
                            // ALL 广播：fire-and-forget，立即写闪存更新UI
                            lora_status = LORA_STATUS_IDLE;
                            update_lora_status_indicator();

                            LoRaFrameData msg_frame = {0};
                            msg_frame.self_id = self_id;
                            msg_frame.target_id = 0x00;
                            struct timeval tv;
                            gettimeofday(&tv, NULL);
                            struct tm *timeinfo = localtime(&tv.tv_sec);
                            if (timeinfo->tm_year >= (2024 - 1900))
                            {
                                msg_frame.month = timeinfo->tm_mon + 1;
                                msg_frame.day = timeinfo->tm_mday;
                                msg_frame.hour = timeinfo->tm_hour;
                                msg_frame.minute = timeinfo->tm_min;
                            }
                            memcpy(msg_frame.data_str, payload, strlen(payload));
                            msg_frame.data_len = strlen(payload);
                            chat_storage_append(&msg_frame);

                            uint32_t sent_packed = (uint32_t)msg_frame.month * 1000000 +
                                                   (uint32_t)msg_frame.day * 10000 +
                                                   (uint32_t)msg_frame.hour * 100 +
                                                   (uint32_t)msg_frame.minute;
                            if (sent_packed > chat_list[0x00].last_time)
                            {
                                chat_list[0x00].last_time = sent_packed;
                                if (current_page_id == PAGE_MENU)
                                    menu_refresh();
                            }
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
void app_main(void)
{
    appQueue = xQueueCreate(10, sizeof(UIEvent));
    init_event_group = xEventGroupCreate();
    lvgl_mutex = xSemaphoreCreateRecursiveMutex();

    // 初始化显示外设
    pwm_init();
    spi_init();
    lcd_init();
    ui_init();

    scr_loading = lv_obj_create(NULL);
    lv_obj_t *spinner = lv_spinner_create(scr_loading);
    lv_spinner_set_anim_params(spinner, 1000, 270); // 1000ms 转一圈，圆弧角度 270 度
    lv_obj_set_size(spinner, 80, 80);
    lv_obj_center(spinner);

    boot_text_label = lv_label_create(scr_loading);
    lv_label_set_text(boot_text_label, "System Booting...");
    lv_obj_set_style_text_font(boot_text_label, &jbm12, 0);
    lv_obj_center(boot_text_label);
    lv_obj_align_to(
        boot_text_label,
        spinner,
        LV_ALIGN_OUT_BOTTOM_MID,
        0,
        20);

    lv_screen_load(scr_loading); // 加载开机动画屏幕

    last_activity_time_us = esp_timer_get_time();

    ESP_LOGI("SLEEP_BOOT", "auto_sleep_timeout: %u", auto_sleep_timeout);

    // 创建LVGL Tick定时器
    const esp_timer_create_args_t periodic_timer_args = {
        .callback = &lvgl_tick_cb,
        .name = "periodic_gui"};
    esp_timer_handle_t periodic_timer;
    esp_timer_create(&periodic_timer_args, &periodic_timer);
    esp_timer_start_periodic(periodic_timer, 1000); // 1000us

    xTaskCreatePinnedToCore(app_main_task, "app_main", 8192, NULL, 5, NULL, 1);

    vTaskDelay(pdMS_TO_TICKS(50));

    xTaskCreatePinnedToCore(peripheral_init_task, "periph_init", 8192, NULL, 5, NULL, 0);

    while (1)
    {
        vTaskDelay(pdMS_TO_TICKS(1000));
    }
}

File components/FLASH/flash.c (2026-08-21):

#include "flash.h"

#include <stdbool.h>
#include "freertos/FreeRTOS.h"
#include "freertos/task.h"
#include "driver/spi_master.h"
#include "esp_log.h"
#include "esp_flash.h"
#include "esp_flash_spi_init.h"
#include "uart.h"
#include "va.h"

#define FLASH_SIZE (8 * 1024 * 1024UL)
#define FLASH_SECTOR_SIZE 4096
#define META_ADDR 0x000000
#define META_SIZE FLASH_SECTOR_SIZE
#define CHAT_BLOCK_A_ADDR META_SIZE
#define CHAT_BLOCK_SIZE ((FLASH_SIZE - META_SIZE) / 2)
#define CHAT_BLOCK_B_ADDR (CHAT_BLOCK_A_ADDR + CHAT_BLOCK_SIZE)

#define META_MAGIC 0x5AA5
#define CHAT_MAGIC 0xAA55

#define PIN_NUM_MISO 41
#define PIN_NUM_MOSI 38
#define PIN_NUM_CLK 39
#define PIN_NUM_CS 40

static esp_flash_t *s_ext_flash = NULL;
static uint32_t s_flash_size = 0;
static meta_t g_meta;
static uint32_t g_meta_offset = 0;
uint32_t g_write_offset;

static inline uint32_t get_active_addr(void)
{
    return (g_meta.active_block == 0)
               ? CHAT_BLOCK_A_ADDR
               : CHAT_BLOCK_B_ADDR;
}

static inline uint32_t get_inactive_addr(void)
{
    return (g_meta.active_block == 0)
               ? CHAT_BLOCK_B_ADDR
               : CHAT_BLOCK_A_ADDR;
}

// 将 LoRaFrameData 的时间打包为 MMDDHHMM 格式的整数
static inline uint32_t pack_frame_time(const LoRaFrameData *frame)
{
    return (uint32_t)frame->month * 1000000 +
           (uint32_t)frame->day * 10000 +
           (uint32_t)frame->hour * 100 +
           (uint32_t)frame->minute;
}

static inline uint16_t chat_record_size(const LoRaFrameData *frame)
{
    return offsetof(LoRaFrameData, data_str) +
           frame->data_len +
           sizeof(frame->checksum) +
           sizeof(frame->data_len) +
           sizeof(uint16_t); // Magic
}

esp_err_t ext_flash_init(void)
{

    spi_bus_config_t buscfg = {
        .mosi_io_num = PIN_NUM_MOSI,
        .miso_io_num = PIN_NUM_MISO,
        .sclk_io_num = PIN_NUM_CLK,
        .quadwp_io_num = -1,
        .quadhd_io_num = -1,
        .max_transfer_sz = 4096,
    };

    ESP_ERROR_CHECK(spi_bus_initialize(SPI3_HOST, &buscfg, SPI_DMA_CH_AUTO));

    esp_flash_spi_device_config_t devcfg = {
        .host_id = SPI3_HOST,
        .cs_io_num = PIN_NUM_CS,
        .io_mode = SPI_FLASH_FASTRD,
        .freq_mhz = 40,
        .input_delay_ns = 0,
    };

    ESP_ERROR_CHECK(spi_bus_add_flash_device(&s_ext_flash, &devcfg));
    ESP_ERROR_CHECK(esp_flash_init(s_ext_flash));
    return esp_flash_get_physical_size(s_ext_flash,
                                       &s_flash_size);
}

esp_err_t ext_flash_read(uint32_t addr, void *buf, size_t len)
{
    if (s_ext_flash == NULL)
        return ESP_ERR_INVALID_STATE;

    return esp_flash_read(
        s_ext_flash,
        buf,
        addr,
        len);
}

esp_err_t ext_flash_write(uint32_t addr,
                          const void *buf,
                          size_t len)
{
    if (s_ext_flash == NULL)
        return ESP_ERR_INVALID_STATE;

    return esp_flash_write(
        s_ext_flash,
        buf,
        addr,
        len);
}

esp_err_t ext_flash_erase_sector(uint32_t addr)
{
    if (s_ext_flash == NULL)
        return ESP_ERR_INVALID_STATE;

    addr &= ~(4096 - 1);

    return esp_flash_erase_region(
        s_ext_flash,
        addr,
        4096);
}

uint32_t ext_flash_size(void)
{
    return s_flash_size;
}

esp_err_t ext_flash_erase_chip(void)
{
    if (s_ext_flash == NULL)
        return ESP_ERR_INVALID_STATE;

    return esp_flash_erase_chip(s_ext_flash);
}

esp_err_t meta_save(const meta_t *meta)
{
    esp_err_t err;

    if (g_meta_offset + sizeof(meta_t) > META_SIZE)
    {
        err = ext_flash_erase_sector(META_ADDR);
        if (err != ESP_OK)
            return err;

        g_meta_offset = 0;
    }

    err = ext_flash_write(META_ADDR + g_meta_offset, meta, sizeof(meta_t));
    if (err != ESP_OK)
        return err;

    g_meta_offset += sizeof(meta_t);

    return ESP_OK;
}

esp_err_t meta_init(void)
{
    meta_t meta;
    g_meta_offset = 0;

    while (g_meta_offset + sizeof(meta_t) <= META_SIZE)
    {
        if (ext_flash_read(META_ADDR + g_meta_offset, &meta, sizeof(meta)) != ESP_OK)
            return ESP_FAIL;
        if (meta.magic != META_MAGIC)
            break;
        if (meta.active_block > 1)
            break;

        g_meta = meta;
        g_meta_offset += sizeof(meta_t);
    }

    // Flash为空，初始化
    if (g_meta_offset == 0)
    {
        g_meta.magic = META_MAGIC;
        g_meta.active_block = 0;
        ESP_ERROR_CHECK(ext_flash_erase_sector(META_ADDR));
        g_meta_offset = 0;

        return meta_save(&g_meta);
    }

    return ESP_OK;
}

uint32_t chat_storage_scan(void)
{
    uint32_t offset = 0;
    uint32_t base = get_active_addr();
    uint8_t tail_len;
    uint16_t magic;
    uint16_t fixed = offsetof(LoRaFrameData, data_str);

    while (offset + fixed < CHAT_BLOCK_SIZE)
    {
        LoRaFrameData frame;
        if (ext_flash_read(base + offset, &frame, fixed) != ESP_OK)
            break;
        if (frame.data_len > 129)
            break;
        uint32_t record_size = chat_record_size(&frame);
        if (offset + record_size > CHAT_BLOCK_SIZE)
            break;

        // 字符串
        if (ext_flash_read(base + offset + fixed,
                           frame.data_str,
                           frame.data_len) != ESP_OK)
            break;

        frame.data_str[frame.data_len] = '\0';

        // 读 checksum
        if (ext_flash_read(base + offset + fixed + frame.data_len,
                           &frame.checksum,
                           sizeof(frame.checksum)) != ESP_OK)
            break;

        // 验证 checksum
        uint8_t crc = calculateCRC8((const uint8_t *)&frame, offsetof(LoRaFrameData, data_str) + frame.data_len);

        if (crc != frame.checksum)
            break;

        // 验证数据长度
        if (ext_flash_read(base + offset + fixed + frame.data_len + sizeof(frame.checksum),
                           &tail_len,
                           sizeof(tail_len)) != ESP_OK)
            break;

        if (tail_len != frame.data_len)
            break;

        // 验证 Magic
        if (ext_flash_read(base + offset + record_size - sizeof(magic),
                           &magic,
                           sizeof(magic)) != ESP_OK)
            break;

        if (magic != CHAT_MAGIC)
            break;

        offset += record_size;

        vTaskDelay(pdMS_TO_TICKS(10));
    }

    return offset;
}

static bool is_flash_region_clean(uint32_t addr, size_t len)
{
    uint8_t buf[32];
    while (len > 0)
    {
        size_t chunk = (len > sizeof(buf)) ? sizeof(buf) : len;
        if (ext_flash_read(addr, buf, chunk) != ESP_OK)
            return false;
        for (size_t i = 0; i < chunk; i++)
        {
            if (buf[i] != 0xFF)
                return false;
        }
        addr += chunk;
        len -= chunk;
    }
    return true;
}
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

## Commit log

2026-07-19 增大了程序分区 更改了字体 迁移event到types 修复了写入偏移不会自动调整的问题 写完了menu和settings 重构了部分ui 更改了nvs.c/.h为mynvs.c/.h以避免命名冲突 按键后重置睡眠超时时间 修改lora为定点传输 能够修改lora的MD0和MD1以正确进入配置/工作/低功耗模式 增加了对时和手调时间 初步添加了超时自动睡觉
    [partitions_user.csv]
2026-07-19 完善了低功耗 添加了亮度调节 删掉了古老的扫描按键注释 调整所有时间都从系统时间获取
2026-07-20 加入了电量检测 修改了一些引脚 删除了一些永远不成立的边界检查和一些未使用的变量 添加了添加/删除联系人的设置
2026-07-21 修改了部分I2C引脚
2026-07-24 引入agents.md 让我品鉴一下真正的vibecoding 修正了部分可能导致看门狗超时的操作 修改了部分引脚 修正了睡觉超时单位换算不对的问题 修正了开机读取新的nvs读不到的问题
    [flash.c, i2c.c, lcd.c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]
2026-07-24 调整LCD颜色
2026-07-28 休眠和心跳优化
    休眠: 键盘行引脚改为RTC GPIO输出低电平，关闭上下拉节省电流(~73μA/脚)
    唤醒后恢复所有12个RTC引脚为数字GPIO，修复列引脚未deinit的问题
    休眠前等待UART发送完毕(20ms控制台+200ms LoRa)
    修正auto_sleep_timeout日志格式(%lld ms→%u s)
    心跳: 启用心跳任务，发送前不再唤醒/休眠LoRa(模块自行管理功耗)
    心跳接收时更新chat_list.last_online(原last_time)
    添加self_id检查，忽略自己的心跳
    项目: 更新.gitignore排除.agents/和skills-lock.json
    修正AGENTS.md组件数为12，移除GAME/组件条目
    [sleep.c, uart.c]
2026-07-28 feat: PGUP/PGDOWN导航, 字符化SHIFT/LOCK图标, LoRa状态指示, ACK重试去重, 自定义标题
    PGUP/PGDOWN: MENU/SETTINGS移动光标, CHAT翻页列表(容器高度-10px)
    字符化SHIFT/LOCK图标: 22x22方形容器, 边框渲染
    SHIFT: 正常→透底边框S, 按下→反色填充S
    LOCK: 空闲→?, 等待候选→0-9, 锁定→反色L
    按键状态通过sentinel(19/20)和循环更新触发, 无轮询开销
    进入设置详情自动退出锁定, 返回恢复锁定
    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
2026-07-28 fix: INA219引脚移出PSRAM区域, 新增内存低水位监控
    INA219: GPIO35/36/37→GPIO1/2/42 避免与Octal PSRAM(33-37)冲突
    新增每隔10s输出内存使用: 当前空闲/启动最低水位/PSRAM剩余
    uart.h: 补充heartbeat_task声明
    移除docs/spec-online-status-and-battery-monitor.md
    [i2c.c, main.c]
2026-07-29 修复了Menu光标不能正常显示的问题；修复了心跳和外设初始化可能使得栈溢出的问题；修复了几个可能导致访问空指针的问题
2026-07-30 更新agents.md；使用py模拟收发和处理消息；添加了一些关于chat界面的调试信息 ；优化按键逻辑；调整用户默认颜色为白色；睡眠中自动醒来发心跳；添加了清空NVS和外置Flash的设置项；修复了初始化Flash的lvgl文字可能导致看门狗超时
2026-07-30 迁移esp-idf v5.5.4到v6.0.2
2026-08-10 更新部分引脚以更好地绘制PCB
2026-08-10 修复了无法触发SEND按键的问题
2026-08-10 添加ALL联系人，用于广播消息（无ACK）；更改了CHAT页面的翻页上下；
2026-08-10 防止睡眠唤醒时重复处理用于唤醒的按键；修复了SPI重复添加device的问题
2026-08-10 更新AGENTS.md
2026-08-10 更新lvgl到9.5.0
2026-08-10 添加了对ALL的py模拟
2026-08-10 更改了wifi.c使之能够通过AP配网
2026-08-10 从CHAT按BACK可以返回MENU；防止在配网时等待太久而自动睡着
2026-08-10 聊天界面显示目标id
2026-08-13 修复了重启后拿不到WIFI配置的问题；打开了电量检测
2026-08-13 格式化代码；修复了一些测试点；删除部分无用代码
2026-08-21 防止单条聊天记录损坏导致的读取和写入异常
2026-08-21 加入关闭心跳定时发送的设置项
2026-08-25 PCB和壳子
    [esp32-s3-lora-chat.f3z, esp32-s3-lora-chat.step, 大-25.stl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]
2026-08-25 更新README
2026-08-25 添加sdkconfig.defaults
2026-08-25 更改了部分字体
